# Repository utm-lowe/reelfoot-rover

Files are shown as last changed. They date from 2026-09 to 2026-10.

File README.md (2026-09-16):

# Reelfoot Rover

The Reelfoot Rover is a robot which is used in the CSCI 458 - Autonomous Mobile 
Robotics at the University of Tennessee at Matin. This robot is a 4wd robot 
with each wheel being independantly controlled via PWM. The robot is controlled
via a Raspberry Pi computer, and power for the motors and all peripherals is drawn
from the power rails of the Raspberr Pi.

This repository contains the circuit board which controls the following:
- 4 Independentally Controlled Motors
- 4 Optical Wheel Encoders
- 3 HC-SR04 Ultrasonic Range Finder (Sonars)

The board is designed to be used along with the Raspberry Pi Sense Hat. You don't
need the sense hat, but I rather like it. So I made sure to not use any of the pins 
used by the sense hat. You can stack this board under the sense hat, or connect it
with a ribbon cable.

This board is licensed under the MIT License and provided in the hope that you'll
find it helpful and use it in your own robotics tinkering.

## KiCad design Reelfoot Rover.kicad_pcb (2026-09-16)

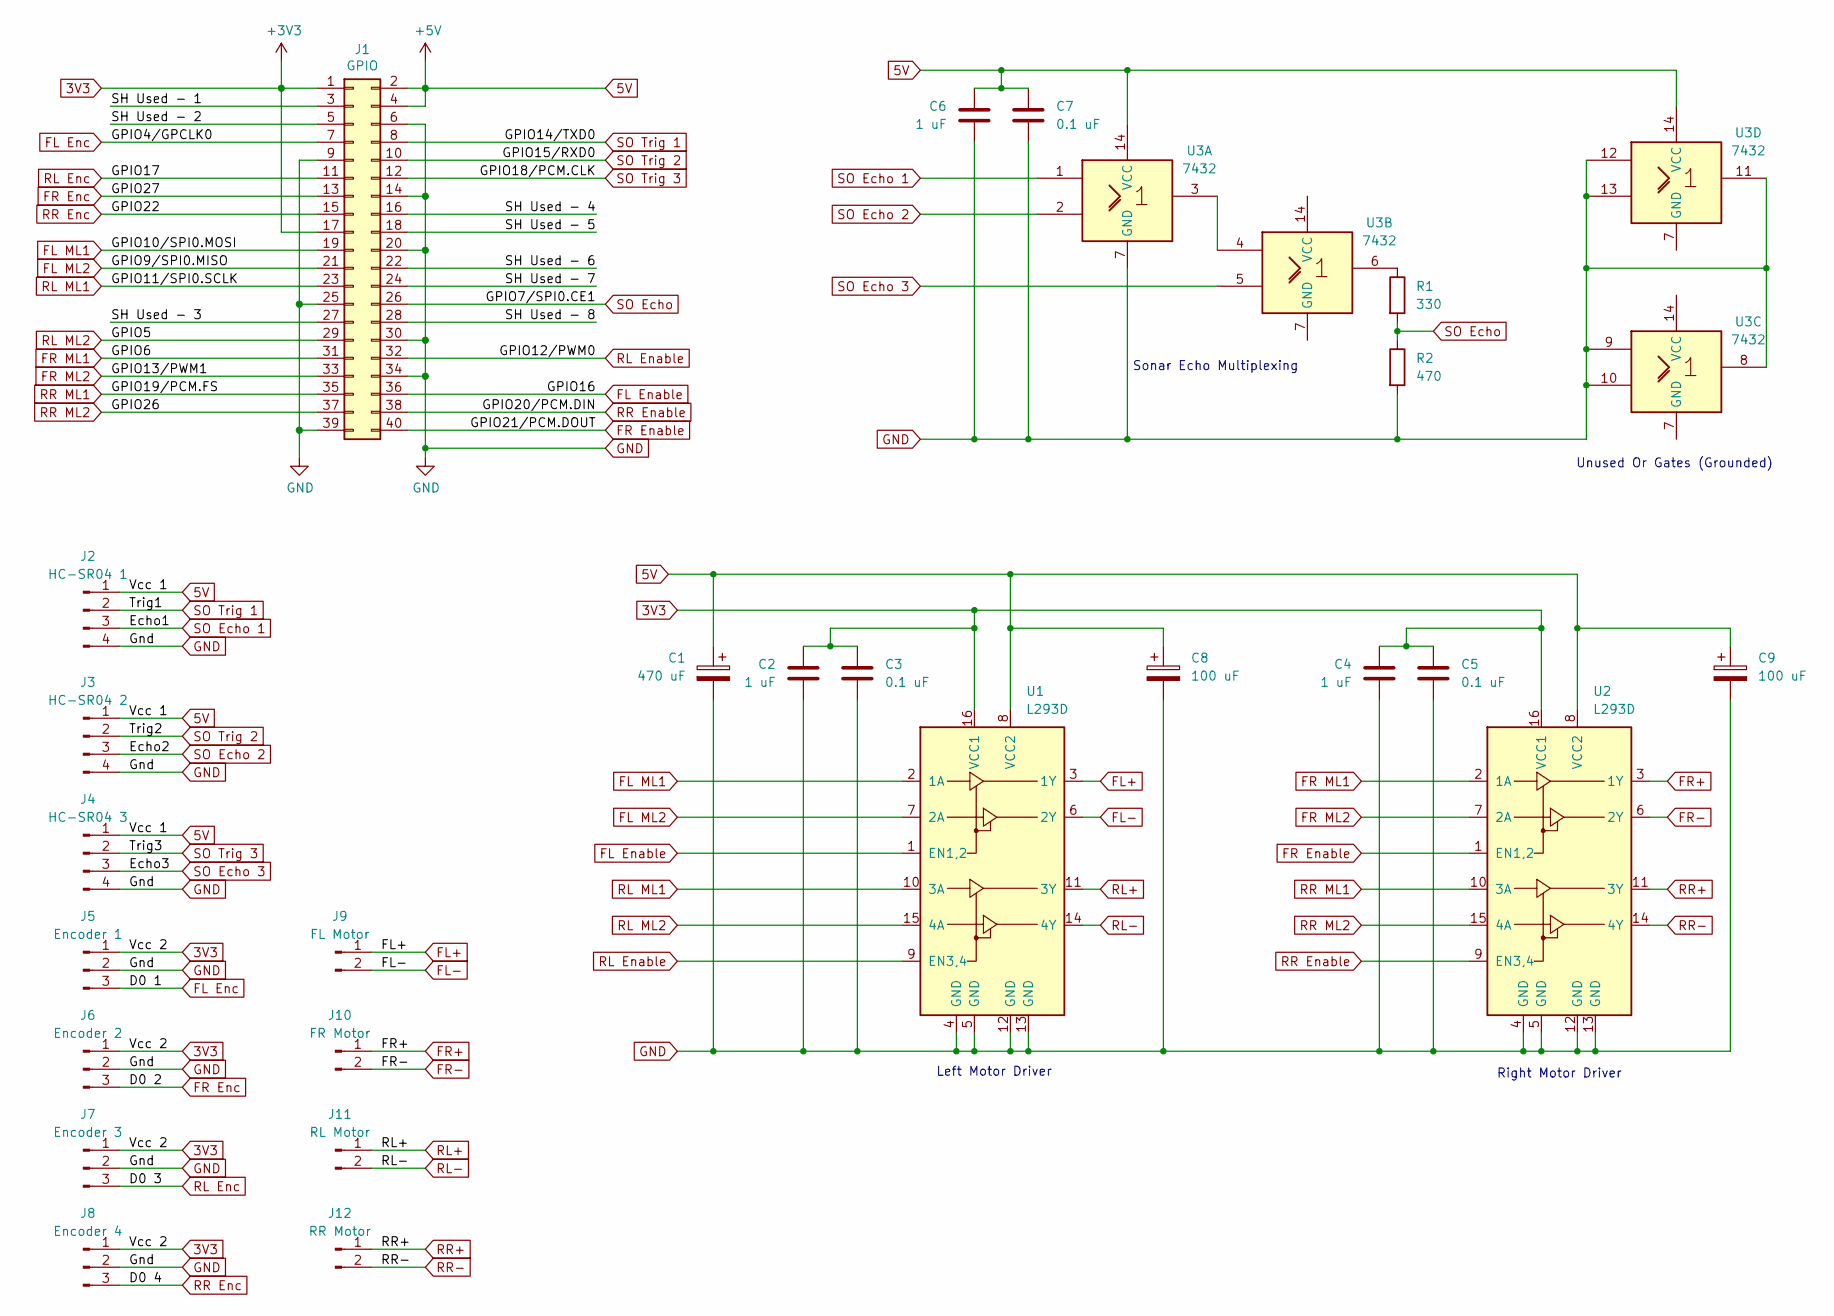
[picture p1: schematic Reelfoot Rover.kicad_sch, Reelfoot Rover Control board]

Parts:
C1: 470 uF; CP_Radial_D8.0mm_P2.50mm
C2, C4, C6: 1 uF; C_Disc_D5.0mm_W2.5mm_P5.00mm
C3, C5, C7: 0.1 uF; C_Disc_D5.0mm_W2.5mm_P5.00mm
C8, C9: 100 uF; CP_Radial_D5.0mm_P2.00mm
J1: GPIO; PinSocket_2x20_P2.54mm_Vertical
J2: HC-SR04 1; PinHeader_1x04_P2.54mm_Vertical
J3: HC-SR04 2; PinHeader_1x04_P2.54mm_Vertical
J4: HC-SR04 3; PinHeader_1x04_P2.54mm_Vertical
J5: Encoder 1; PinHeader_1x03_P2.54mm_Vertical
J6: Encoder 2; PinHeader_1x03_P2.54mm_Vertical
J7: Encoder 3; PinHeader_1x03_P2.54mm_Vertical
J8: Encoder 4; PinHeader_1x03_P2.54mm_Vertical
J9: FL Motor; PinHeader_1x02_P2.54mm_Vertical
J10: FR Motor; PinHeader_1x02_P2.54mm_Vertical
J11: RL Motor; PinHeader_1x02_P2.54mm_Vertical
J12: RR Motor; PinHeader_1x02_P2.54mm_Vertical
R1: 330; R_Axial_DIN0207_L6.3mm_D2.5mm_P7.62mm_Horizontal
R2: 470; R_Axial_DIN0207_L6.3mm_D2.5mm_P7.62mm_Horizontal
U1, U2: L293D; DIP-16_W7.62mm
U3: 7432; DIP-14_W7.62mm

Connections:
3V3: C2.1, C3.1, C4.1, C5.1, J1.1, J1.17, J5.1, J6.1, J7.1, J8.1, U1.16 (VCC1), U2.16 (VCC1)
5V: C1.1, C6.1, C7.1, C8.1, C9.1, J1.2, J1.4, J2.1, J3.1, J4.1, U1.8 (VCC2), U2.8 (VCC2), U3.14 (VCC)
/SH Used - 1: J1.3
/SH Used - 2: J1.5
/SH Used - 3: J1.27
/SH Used - 4: J1.16
/SH Used - 5: J1.18
/SH Used - 6: J1.22
/SH Used - 7: J1.24
/SH Used - 8: J1.28
FL Enable: J1.36, U1.1 (EN1,2)
FL Enc: J1.7, J5.3
FL ML1: J1.19, U1.2 (1A)
FL ML2: J1.21, U1.7 (2A)
FL+: J9.1, U1.3 (1Y)
FL-: J9.2, U1.6 (2Y)
FR Enable: J1.40, U2.1 (EN1,2)
FR Enc: J1.13, J6.3
FR ML1: J1.31, U2.2 (1A)
FR ML2: J1.33, U2.7 (2A)
FR+: J10.1, U2.3 (1Y)
FR-: J10.2, U2.6 (2Y)
GND: C1.2, C2.2, C3.2, C4.2, C5.2, C6.2, C7.2, C8.2, C9.2, J1.6, J1.9, J1.14, J1.20, J1.25, J1.30, J1.34, J1.39, J2.4, J3.4, J4.4, J5.2, J6.2, J7.2, J8.2, R2.2, U1.4 (GND), U1.5 (GND), U1.12 (GND), U1.13 (GND), U2.4 (GND), U2.5 (GND), U2.12 (GND), U2.13 (GND), U3.7 (GND), U3.8, U3.9, U3.10, U3.11, U3.12, U3.13
unnamed: R1.1, U3.6
unnamed: U3.3, U3.4
RL Enable: J1.32, U1.9 (EN3,4)
RL Enc: J1.11, J7.3
RL ML1: J1.23, U1.10 (3A)
RL ML2: J1.29, U1.15 (4A)
RL+: J11.1, U1.11 (3Y)
RL-: J11.2, U1.14 (4Y)
RR Enable: J1.38, U2.9 (EN3,4)
RR Enc: J1.15, J8.3
RR ML1: J1.35, U2.10 (3A)
RR ML2: J1.37, U2.15 (4A)
RR+: J12.1, U2.11 (3Y)
RR-: J12.2, U2.14 (4Y)
SO Echo: J1.26, R1.2, R2.1
SO Echo 1: J2.3, U3.1
SO Echo 2: J3.3, U3.2
SO Echo 3: J4.3, U3.5
SO Trig 1: J1.8, J2.2
SO Trig 2: J1.10, J3.2
SO Trig 3: J1.12, J4.2

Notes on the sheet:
Unused Or Gates (Grounded)
Right Motor Driver
Sonar Echo Multiplexing
Left Motor Driver

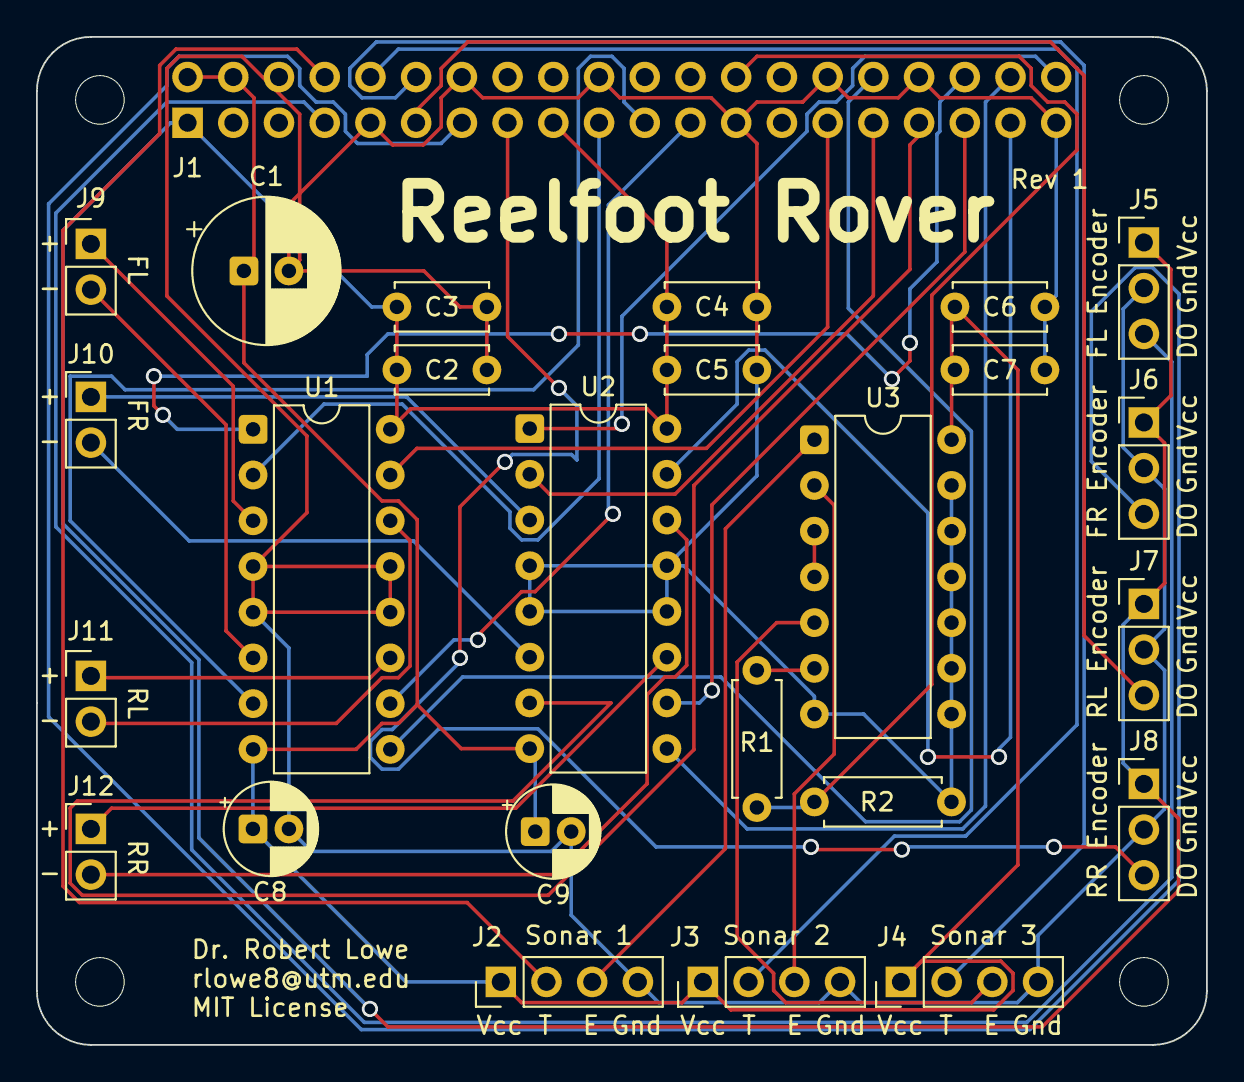
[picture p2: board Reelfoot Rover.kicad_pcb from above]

Board: 2 copper layers, 65.0 x 56.0 mm, 30 parts (1 on the bottom side), 36 nets.

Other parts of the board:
MH1, MH2, MH3, MH4: MountingHole_2.7mm_M2.5

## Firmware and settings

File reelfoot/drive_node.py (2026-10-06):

#!/usr/bin/env python3
"""
Reelfoot Rover drive node.

Subscribes to geometry_msgs/Twist on cmd_vel and turns it into mecanum
wheel commands for the four motors in reelfoot.motors.

ROS conventions (REP 103): linear.x forward, linear.y left, angular.z
counterclockwise. Speeds are open loop: max_linear and max_angular set
which velocities map to full power.
"""
import rclpy
from rclpy.node import Node
from geometry_msgs.msg import Twist

from . import motors as m


class DriveNode(Node):
    def __init__(self):
        super().__init__('drive')
        self.declare_parameter('max_linear', 0.5)    # m/s mapped to full power
        self.declare_parameter('max_angular', 2.0)   # rad/s mapped to full power
        self.declare_parameter('min_pwm', 25.0)      # % duty where the motors start to turn
        self.declare_parameter('timeout', 1.0)       # s without cmd_vel before stopping
        self.declare_parameter('invert', [False, False, False, False])  # FL FR RL RR

        self.max_linear = self.get_parameter('max_linear').value
        self.max_angular = self.get_parameter('max_angular').value
        self.min_pwm = self.get_parameter('min_pwm').value
        self.timeout = self.get_parameter('timeout').value
        self.invert = list(self.get_parameter('invert').value)

        self.motors = [m.FL, m.FR, m.RL, m.RR]
        self.moving = False
        self.last_cmd = self.get_clock().now()

        self.create_subscription(Twist, 'cmd_vel', self.on_cmd, 10)
        self.create_timer(0.1, self.watchdog)
        self.get_logger().info('drive ready, listening on cmd_vel')

    def on_cmd(self, msg):
        """Mecanum inverse kinematics, normalized to [-1, 1] per wheel."""
        vx = msg.linear.x / self.max_linear
        vy = msg.linear.y / self.max_linear
        wz = msg.angular.z / self.max_angular

        wheels = [
            vx - vy - wz,   # FL
            vx + vy + wz,   # FR
            vx + vy - wz,   # RL
            vx - vy + wz,   # RR
        ]
        # if any wheel would exceed full power, scale all of them down
        # together so the direction of motion is preserved
        peak = max(1.0, *(abs(w) for w in wheels))
        self.drive([w / peak for w in wheels])
        self.last_cmd = self.get_clock().now()

    def drive(self, wheels):
        self.moving = any(abs(w) > 0.01 for w in wheels)
        for motor, w, inv in zip(self.motors, wheels, self.invert):
            if inv:
                w = -w
            if abs(w) < 0.01:
                motor.set_speed(0)
                motor.set_direction(m.BRAKE)
            else:
                motor.set_direction(m.FORWARD if w > 0 else m.REVERSE)
                # skip the dead zone where the motors hum but don't turn
                motor.set_speed(self.min_pwm + (100 - self.min_pwm) * abs(w))

    def stop(self):
        self.drive([0.0, 0.0, 0.0, 0.0])

    def watchdog(self):
        """Stop if the commands stop coming (dropped teleop, crashed planner)."""
        idle = (self.get_clock().now() - self.last_cmd).nanoseconds / 1e9
        if self.moving and idle > self.timeout:
            self.get_logger().warning('cmd_vel timed out, stopping')
            self.stop()

    def destroy_node(self):
        self.stop()
        super().destroy_node()


def main():
    rclpy.init()
    node = DriveNode()
    try:
        rclpy.spin(node)
    except KeyboardInterrupt:
        pass
    finally:
        node.destroy_node()
        rclpy.try_shutdown()


if __name__ == '__main__':
    main()

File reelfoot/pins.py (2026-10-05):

"""
Reelfoot Rover pin definitions for interfacing with the GPIO pins.
All pins are given as their GPIO (Broadcom) number. The pins defined 
are:

    Encoder Pins
    ============
    FL_Enc - Front Left Encoder Input
    RL_Enc - Rear Left Encoder Input
    FR_Enc - Front Right Encoder Input
    RR_Enc - Rear Right Encoder Input

    Sonar Pins
    ==========
    SO1_Trig - Sonar 1 Trigger
    SO2_Trig - Sonar 2 Trigger
    SO3_Trig - Sonar 3 Trigger
    SO_Echo  - Sonar echo pin

    Motor Direction Pins
    ====================
    FL_ML1 - Front Left Motor Logic 1
    FL_ML2 - Front Left Motor Logic 2
    RL_ML1 - Rear Left Motor Logic 1
    RL_ML2 - Rear Left Motor Logic 2
    FR_ML1 - Front Right Motor Logic 1
    FR_ML2 - Front Right Motor Logic 2
    RR_ML1 - Rear Right Motor Logic 1
    RR_ML2 - Rear Right Motor Logic 2

    Motor Speed Pins (PWM)
    ======================
    FL_Speed - Front Left Speed
    RL_Speed - Rear Left Speed
    FR_Speed - Front Right Speed
    RR_Speed - Rear Right Speed
"""
# Encoder Inputs
FL_Enc=4
RL_Enc=17
FR_Enc=27
RR_Enc=22

# Sonar Pins
SO1_Trig = 14
SO2_Trig = 15
SO3_Trig = 18
SO_Echo = 7

# Motor Direction Pins
FL_ML1 = 10
FL_ML2 = 9
RL_ML1 = 11
RL_ML2 = 5
FR_ML1 = 6
FR_ML2 = 13
RR_ML1 = 19
RR_ML2 = 26

# Motor Speed (PWM) Pins
FL_Speed = 16
FR_Speed = 21
RL_Speed = 12
RR_Speed = 20

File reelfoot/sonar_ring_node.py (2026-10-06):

#!/usr/bin/env python3
"""Reelfoot Rover sonar ring: publishes a sensor_msgs/Range for each sonar."""
import math
import threading
import time

import lgpio
import rclpy
from rclpy.node import Node
from rclpy.qos import qos_profile_sensor_data
from sensor_msgs.msg import Range

from . import pins as p

SPEED_OF_SOUND = 343.0  # m/s at about 20 C


class SonarRing:
    """Sequentially fired sonars whose echo lines are OR'd onto one GPIO."""

    def __init__(self, triggers, echo, chip=0):
        self.triggers = triggers
        self.echo = echo
        self.done = threading.Event()
        self.start = None
        self.end = None

        self.handle = lgpio.gpiochip_open(chip)
        for t in triggers:
            lgpio.gpio_claim_output(self.handle, t, 0)
        time.sleep(0.2)   # let any echo from a claim-glitch ping finish
        lgpio.gpio_claim_alert(self.handle, echo, lgpio.BOTH_EDGES,
                               lgpio.SET_PULL_NONE)
        time.sleep(0.1)
        self.cb = lgpio.callback(self.handle, echo, lgpio.BOTH_EDGES, self._edge)
        time.sleep(0.1)   # give lgpio's callback thread time to come up

    def _edge(self, chip, gpio, level, tick):
        """lgpio alert callback; tick is in nanoseconds."""
        if level == 1:
            self.start = tick
        elif self.start is not None:      # ignore orphan falling edges
            self.end = tick
            self.done.set()

    def ping(self, idx, timeout=0.04):
        """Fire sonar idx; return distance in meters, or inf on timeout."""
        # don't fire while a previous echo is still holding the OR'd line high
        deadline = time.monotonic() + 0.25
        while (lgpio.gpio_read(self.handle, self.echo)
               and time.monotonic() < deadline):
            time.sleep(0.001)
        self.start = self.end = None
        self.done.clear()
        lgpio.tx_pulse(self.handle, self.triggers[idx], 10, 10, 0, 1)
        if not self.done.wait(timeout):
            return math.inf
        return (self.end - self.start) / 1e9 * SPEED_OF_SOUND / 2

    def close(self):
        self.cb.cancel()
        for t in self.triggers:
            lgpio.gpio_write(self.handle, t, 0)
        lgpio.gpiochip_close(self.handle)


class SonarRingNode(Node):
    def __init__(self):
        super().__init__("sonar_ring")
        self.declare_parameter("timeout", 0.04)        # s; 0.04 covers ~4 m
        self.declare_parameter("min_range", 0.02)      # m
        self.declare_parameter("max_range", 4.0)       # m
        self.declare_parameter("field_of_view", 0.26)  # rad, about 15 degrees

        self.timeout = self.get_parameter("timeout").value
        self.min_range = self.get_parameter("min_range").value
        self.max_range = self.get_parameter("max_range").value
        self.fov = self.get_parameter("field_of_view").value

        triggers = (p.SO1_Trig, p.SO2_Trig, p.SO3_Trig)
        self.ring = SonarRing(triggers, p.SO_Echo)

        # names match the pin labels: sonar_1, sonar_2, sonar_3
        # (ROS name tokens can't start with a digit, so no sonar/1)
        self.names = [f"sonar_{i + 1}" for i in range(len(triggers))]
        self.pubs = [self.create_publisher(Range, n, qos_profile_sensor_data)
                     for n in self.names]

        self.running = True
        self.thread = threading.Thread(target=self.scan_loop, daemon=True)
        self.thread.start()

    def scan_loop(self):
        while self.running and rclpy.ok():
            for i, (name, pub) in enumerate(zip(self.names, self.pubs)):
                if not self.running:
                    return
                stamp = self.get_clock().now().to_msg()
                d = self.ring.ping(i, self.timeout)

                msg = Range()
                msg.header.stamp = stamp
                msg.header.frame_id = name
                msg.radiation_type = Range.ULTRASOUND
                msg.field_of_view = self.fov
                msg.min_range = self.min_range
                msg.max_range = self.max_range
                # REP 117: -inf = too close, +inf = nothing detected
                if d < self.min_range:
                    msg.range = -math.inf
                elif d > self.max_range:
                    msg.range = math.inf
                else:
                    msg.range = d
                pub.publish(msg)

    def destroy_node(self):
        self.running = False
        self.thread.join(timeout=1.0)   # finish the current ping before closing GPIO
        self.ring.close()
        super().destroy_node()


def main():
    rclpy.init()
    node = SonarRingNode()
    try:
        rclpy.spin(node)
    except KeyboardInterrupt:
        pass
    finally:
        node.destroy_node()
        rclpy.try_shutdown()


if __name__ == "__main__":
    main()

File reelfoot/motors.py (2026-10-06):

"""
The Reelfoot Rover controls four motors:
    FL - Front Left
    FR - Front Right
    RL - Rear Left
    RR - Rear Right
These motors have an accompanying speed and direction setting.
"""
import lgpio
from . import pins as p

# Constants
FORWARD = (1, 0)
REVERSE = (0, 1)
BRAKE = (1, 1)
PWM_FREQUENCY = 100

class Motor:
    """
    Basic motor control via PWM on the dual H-Bridge.
    """
    def __init__(self, handle, ml1, ml2, sl):
        """
        Initialize the motor.

        Parameters:
          - handle: The lgpio handle used to control the motor.
          - ml1: Motor logic line 1 of the H-Bridge.
          - ml2: Motor logic line 2 of the H-bridge.
          - sl:  The Speed / Enable line of the H-Bridge.
        """

        # initialize class fields
        self.__handle = handle
        self.__ml1 = ml1
        self.__ml2 = ml2
        self.__sl = sl

        # claim output pins for the motor
        lgpio.gpio_claim_output(handle, ml1)
        lgpio.gpio_claim_output(handle, ml2)
        lgpio.gpio_claim_output(handle, sl)

        # initially, we are stopped
        self.set_direction(BRAKE)
        self.set_speed(0)

    def set_direction(self, direction):
        """
        Set the direction of the motor to the given direction tuple for the ml1
        and ml2 pins.
        """
        self.__direction = direction
        lgpio.gpio_write(self.__handle, self.__ml1, self.__direction[0])
        lgpio.gpio_write(self.__handle, self.__ml2, self.__direction[1])

    def set_speed(self, speed):
        """
        Set the speed of the motor to the given speed (0-100).
        """
        self.__speed = speed
        lgpio.tx_pwm(self.__handle, self.__sl, PWM_FREQUENCY, speed)

    def get_direction(self):
        return self.__direction
    
    def get_speed(self):
        return self.__speed

# define the motors
handle = lgpio.gpiochip_open(0)
FL=Motor(handle, p.FL_ML1, p.FL_ML2, p.FL_Speed)
FR=Motor(handle, p.FR_ML1, p.FR_ML2, p.FR_Speed)
RL=Motor(handle, p.RL_ML1, p.RL_ML2, p.RL_Speed)
RR=Motor(handle, p.RR_ML1, p.RR_ML2, p.RR_Speed)

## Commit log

2026-09-04 first complete draft
    [Reelfoot Rover.kicad_sch]
2026-09-07 Corrected capacitor connections and values.
    [Reelfoot Rover.kicad_sch]
2026-09-13 Footprint selection and beginning the PCB layout.
    [Reelfoot Rover.kicad_pcb, Reelfoot Rover.kicad_sch]
2026-09-14 Placed components, modified resistor footprint
    [Reelfoot Rover.kicad_pcb, Reelfoot Rover.kicad_sch]
2026-09-14 Corrected PWM inputs for motors, and updated part numbers to read better.
    [Reelfoot Rover.kicad_pcb, Reelfoot Rover.kicad_sch]
2026-09-15 Routing more connections
    [Reelfoot Rover.kicad_pcb, Reelfoot Rover.kicad_sch]
2026-09-15 More Routing!
    [Reelfoot Rover.kicad_pcb]
2026-09-16 Completed traces
    [Reelfoot Rover.kicad_pcb]
2026-09-16 Generated Gerbers for PCBWay
    [Reelfoot Rover-B_Cu.gbl, Reelfoot Rover-B_Mask.gbs, Reelfoot Rover-B_Silkscreen.gbo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]
2026-10-05 motor class
2026-10-06 added sonar ring handling
2026-10-06 fancier with pulses and threading events
2026-10-06 sonar ring node
2026-10-28 initial version of the encoder node
2026-10-28 drive node now publishes direction for each wheel
